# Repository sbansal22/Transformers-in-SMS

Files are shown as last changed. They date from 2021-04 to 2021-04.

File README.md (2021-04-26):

# Transformers-in-SMS
Transformers in SMS (CC1310-01) Olin 2020-2021 Co-Curricular

#### Schematic
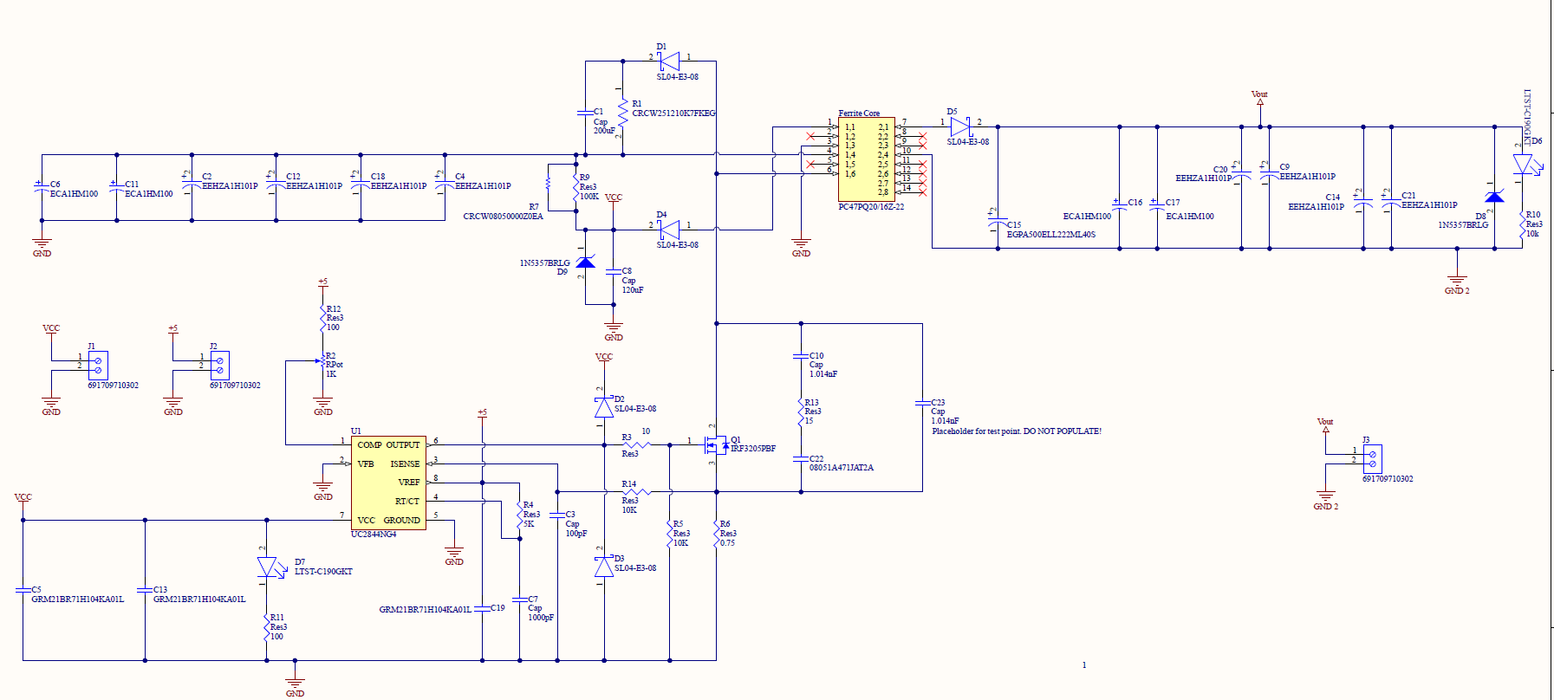
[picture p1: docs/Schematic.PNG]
Schematic


#### Routing
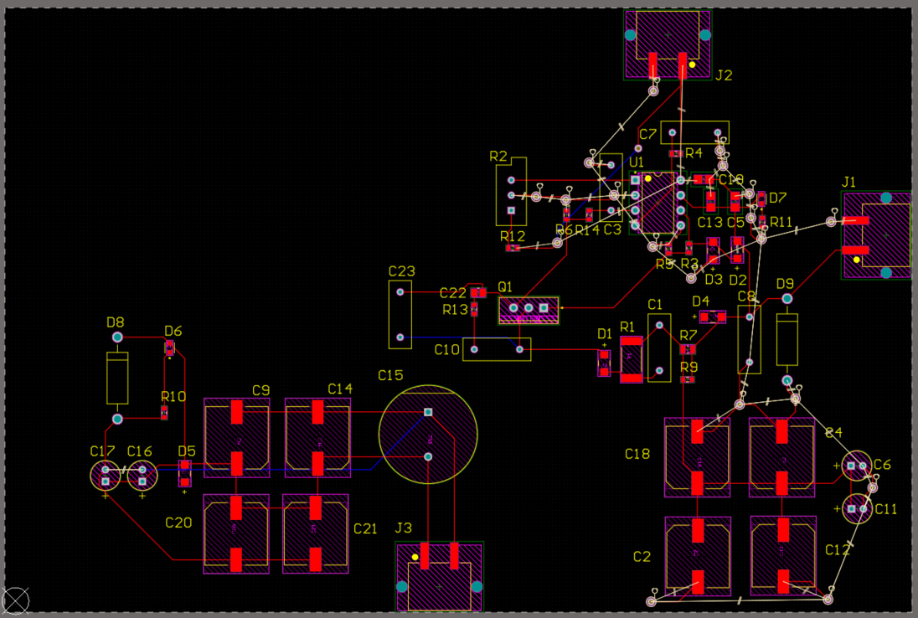
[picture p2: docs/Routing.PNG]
Routing


#### Layout
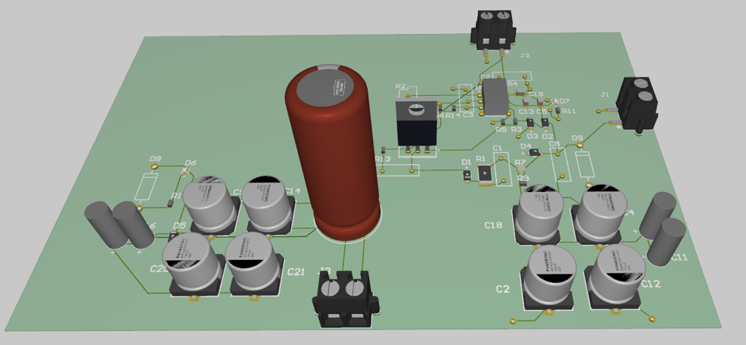
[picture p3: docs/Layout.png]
Layout


## Ordering PCBs From JLCPCB

For ordering the boards, go to JLCPCB.com (https://jlcpcb.com/RAT), and click on "Quote Now" button.

jlcpcb quote

JLCPCB (ShenzhenJLC Electronics Co., Ltd.), is the largest PCB prototype enterprise in China, and a high-tech manufacturer specializing in quick PCB prototype and small-batch PCB production. You can order a minimum of 5 PCBs for just $2.

First: Upload the gerber files for the board by clicking the "Add gerber file" button. You’ll notice a message at the bottom if the file is successfully uploaded.

jlcpbc gerber

A correctly uploaded gerber folder renders the board as follows:

jlcpcb render

Second: In order to get the board assembled (optional, based on the project requirements), select the "SMT Assembly option. It is important to select the side of the PCB that needs to be assembled, as well as the quantity for SMT. Press the "Confirm" button, then press the "Next" button.

jlcpcb smt

Third: upload the BOM (Bill of Material) and CPL (Component Placement List) files and click the "Next" button. It is necessary to make sure that each of these files follow the jlcpcb specified BOM and CPL formats, respectively:

- [Sample BOM](https://jlcpcb.com//video/JLCSMT_Sample_BOM1.xlsx?_ga=2.42560357.1905056644.1612161700-100444678.1610257845)
- [Sample CPL](https://jlcpcb.com//video/JLCSMT_Sample_CPL1.xlsx?_ga=2.42560357.1905056644.1612161700-100444678.1610257845)
- [SMT FAQ's](https://support.jlcpcb.com/category/78-smt-assembly?_ga=2.42560357.1905056644.1612161700-100444678.1610257845)

Note: If there is an issue with the BOM/CPL formatting, the the page will keep erroring out until it is resolved.

jlcpcb bom

Fourth: The parts are automatically detected through the uploaded BOM. They are also matched against jlcpcb's in-stock parts. It is important to go through each row and confirm if the auto-detected parts are the desired parts. Some parts will remain undetected if they cannot be assembled through SMT and require manual assembly post-deilvery.

jlcpcb parts

Fifth: The website renders an assembled board using the CPL file. This feature can be used to review the placement of the components (including orientation). Once carefull reviewed, the next step is to download a list of parts remaining to be assembled towards the bottom of this page view. It is important to place an order for the remaining components to be manually assembled upon delivery.

jlcpcb review

Sixth: Click on the “Save to Cart” button. Then, click on the "Secure Checkout" button.

jlcpcb checkout

Last: Add the payment details and choose the suitable delivery method (this includes FedEx, DHL, and standard mail options). Then, place the order.

Optional: To review the production status of the board, click on the "Order History" button under username. Then, click on In Production > view progress to obtain timestamps for each of the production steps in real time.

jlcpcb production

jlcpcb production progress

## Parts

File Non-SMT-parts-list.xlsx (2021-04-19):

Designator | Comment | Footprint | Quantity
D2,D3,D5,D6,D7 | SS2FL4-M3/H | SODFL3718X108N | 5
R10 | CRCW251210K7FKEG | CRCW251210K7FKEG | 1
C8,C9,C10,C11,C20,C21,C22,C23 | EEHZA1H101P | CAPAE1030X1050N | 8
C1,C2,C3 | GRM21BR71H104KA01L | 0805_C | 3
U2 | PC47PQ20_16Z-22 | CPVPQ20161S14PZ | 0
J4 | CONN_01X02_MALE | PINHEADER_1X02_P2.54MM_VERTICAL | 0
Q1 | IRF3205 | TO-220-3_VERTICAL | 0
C6,C7,C18,C19 | ECA1HM100 | CAPPRD200W50D500H1100B | 0
C13 | 120UF | CAPPRD500W60D1000H1800 | 0
U1 | UC2844NG4 | DIP794W45P254L959H508Q8 | 0
D4,D8 | 1N5357BRLG | DIOAD1720W120L750D440P | 0
DESIGNATOR | COMMENT | FOOTPRINT | 0
J1,J2,J3 | SCREW_TERMINAL_01X02 | TERMINALBLOCK_PHOENIX_MKDS-1,5-2_1X02_P5.00MM_HORIZONTAL | 0
VR1 | 3362P-1-102LF | TRIM_3362P-1-102LF | 0

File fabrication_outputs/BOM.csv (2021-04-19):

Comment | Designator | Footprint | LCSC Part # | LCSC Part Type
PC47PQ20_16Z-22 | U2 | CPVPQ20161S14PZ
GRM21BR71H104KA01L | C1,C2,C3 | 0805_C
1000pF | C4 | 0805_C
100pF | C5 | 0805_C
EEHZA1H101P | C8,C9,C10,C11,C20,C21,C22,C23 | CAPAE1030X1050N
1.014nF | C14 | 0805_C
08051A471JAT2A | C15 | 0805_C
EGPA500ELL222ML40S | C17 | C_Elec_10x10.2
Screw_Terminal_01x02 | J1,J2,J3 | TerminalBlock_Phoenix_MKDS-1,5-2_1x02_P5.00mm_Horizontal
IRF3205 | Q1 | TO-220-3_Vertical
100 | R1 | R_0805_OEM
R_100 | R2 | R_0805_OEM
R_4.7K | R3 | R_0805_OEM
10 | R4 | R_0805_OEM
10K | R5,R6 | R_0805_OEM
0.05 | R7 | R_0805_OEM
CRCW08050000Z0EA | R8 | CRCW08050000Z0EA
R_100K | R9 | R_0805_OEM
CRCW251210K7FKEG | R10 | CRCW251210K7FKEG
15 | R11 | R_0805_OEM
R_10K | R12 | R_0805_OEM
UC2844NG4 | U1 | DIP794W45P254L959H508Q8
ECA1HM100 | C6,C7,C18,C19 | CAPPRD200W50D500H1100B
LTST-C190GKT | D1,D9 | LEDM1608X80
SS2FL4-M3/H | D2,D3,D5,D6,D7 | SODFL3718X108N
1N5357BRLG | D4,D8 | DIOAD1720W120L750D440P
3362P-1-102LF | VR1 | TRIM_3362P-1-102LF
Conn_01x02_Male | J4 | PinHeader_1x02_P2.54mm_Vertical
120uF | C13 | CAPPRD500W60D1000H1800
200uF | C12 | CAPAE1350X1400N

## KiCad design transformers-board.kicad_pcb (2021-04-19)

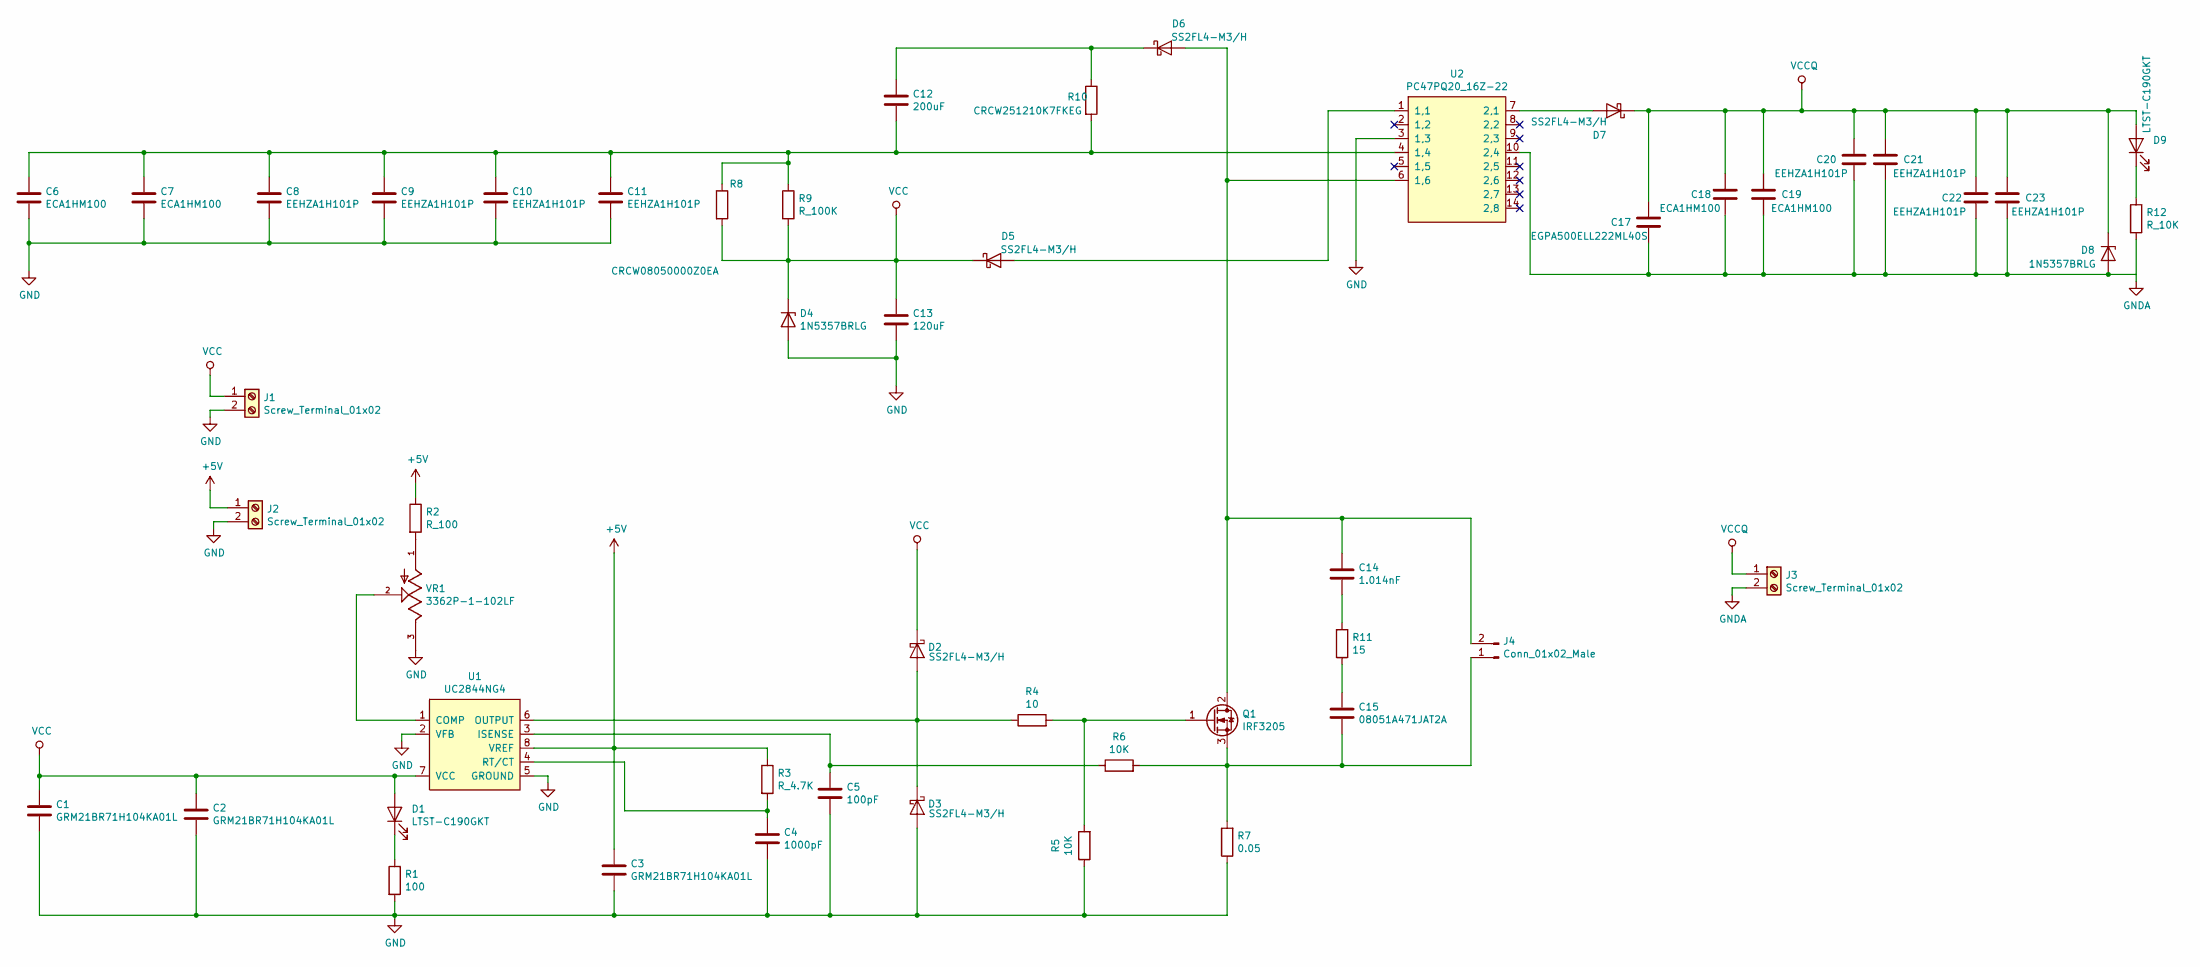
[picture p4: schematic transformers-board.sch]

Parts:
C1, C2, C3: GRM21BR71H104KA01L; C_0805_2012Metric
C4: 1000pF; C_0805_2012Metric
C5: 100pF; C_0805_2012Metric
C6, C7, C18, C19: ECA1HM100; CAPPRD200W50D500H1100B
C8, C9, C10, C11, C20, C21, C22, C23: EEHZA1H101P; CAPAE1030X1050N
C12: 200uF; CAPAE1350X1400N
C13: 120uF; CAPPRD500W60D1000H1800
C14: 1.014nF; C_0805_2012Metric
C15: 08051A471JAT2A; C_0805_2012Metric
C17: EGPA500ELL222ML40S; C_Elec_10x10.2
D1, D9: LTST-C190GKT; LEDM1608X80
D2, D3, D5, D6, D7: SS2FL4-M3/H; SODFL3718X108N
D4, D8: 1N5357BRLG; DIOAD1720W120L750D440P
J1, J2, J3: Screw_Terminal_01x02; TerminalBlock_Phoenix_MKDS-1,5-2_1x02_P5.00mm_Horizontal
J4: Conn_01x02_Male; PinHeader_1x02_P2.54mm_Vertical
Q1: IRF3205; TO-220-3_Vertical
R1: 100; R_0805_OEM; MPN RNCP0805FTD100RCT-ND
R2: R_100; R_0805_OEM; MPN RNCP0805FTD100RCT-ND
R3: R_4.7K; R_0805_OEM; MPN 311-4.7KARCT-ND
R4: 10; R_0805_OEM; MPN RNCP0805FTD100RCT-ND
R5, R6: 10K; R_0805_OEM; MPN RNCP0805FTD100RCT-ND
R7: 0.05; R_0805_OEM; MPN RNCP0805FTD100RCT-ND
R8: CRCW08050000Z0EA
R9: R_100K; R_0805_OEM; MPN P100KCCT-ND
R10: CRCW251210K7FKEG
R11: 15; R_0805_OEM; MPN RNCP0805FTD100RCT-ND
R12: R_10K; R_0805_OEM; MPN CRS0805-FX-1002ELFCT-ND
U1: UC2844NG4; DIP794W45P254L959H508Q8
U2: PC47PQ20_16Z-22; CPVPQ20161S14PZ
VR1: 3362P-1-102LF; TRIM_3362P-1-102LF; PARTREV 08/26/10

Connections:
+5V: C3.1, J2.1, R2.1, R3.1, U1.8 (VREF)
GND: C1.2, C2.2, C3.2, C4.2, C5.2, C6.2, C7.2, C8.2, C9.2, C10.2, C11.2, C13.2, D3.2 (A), D4.2 (A), J1.2, J2.2, R1.2, R5.1, R7.1, U1.2 (VFB), U1.5 (GROUND), U2.3 (1,3), VR1.3
GNDA: C17.2, C18.2, C19.2, C20.2, C21.2, C22.2, C23.2, D8.2 (A), J3.2, R12.2, U2.10 (2,4)
unnamed: C4.1, R3.2, U1.4 (RT/CT)
unnamed: C5.1, R6.1, U1.3 (ISENSE)
unnamed: C6.1, C7.1, C8.1, C9.1, C10.1, C11.1, C12.2, R8.1, R9.1, R10.2, U2.4 (1,4)
unnamed: C12.1, D6.1 (K), R10.1
unnamed: C14.1, D6.2 (A), J4.2, Q1.2 (D), U2.6 (1,6)
unnamed: C14.2, R11.2
unnamed: C15.1, R11.1
unnamed: C15.2, J4.1, Q1.3 (S), R6.2, R7.2
unnamed: D1.1 (K), R1.1
unnamed: D2.2 (A), D3.1 (K), R4.1, U1.6 (OUTPUT)
unnamed: D5.2 (A), U2.1 (1,1)
unnamed: D7.2 (A), U2.7 (2,1)
unnamed: D9.1 (K), R12.1
unnamed: Q1.1 (G), R4.2, R5.2
unnamed: R2.2, VR1.1
unnamed: U1.1 (COMP), VR1.2
VCC: C1.1, C2.1, C13.1, D1.2 (A), D2.1 (K), D4.1 (K), D5.1 (K), J1.1, R8.2, R9.2, U1.7 (VCC)
VCCQ: C17.1, C18.1, C19.1, C20.1, C21.1, C22.1, C23.1, D7.1 (K), D8.1 (K), D9.2 (A), J3.1

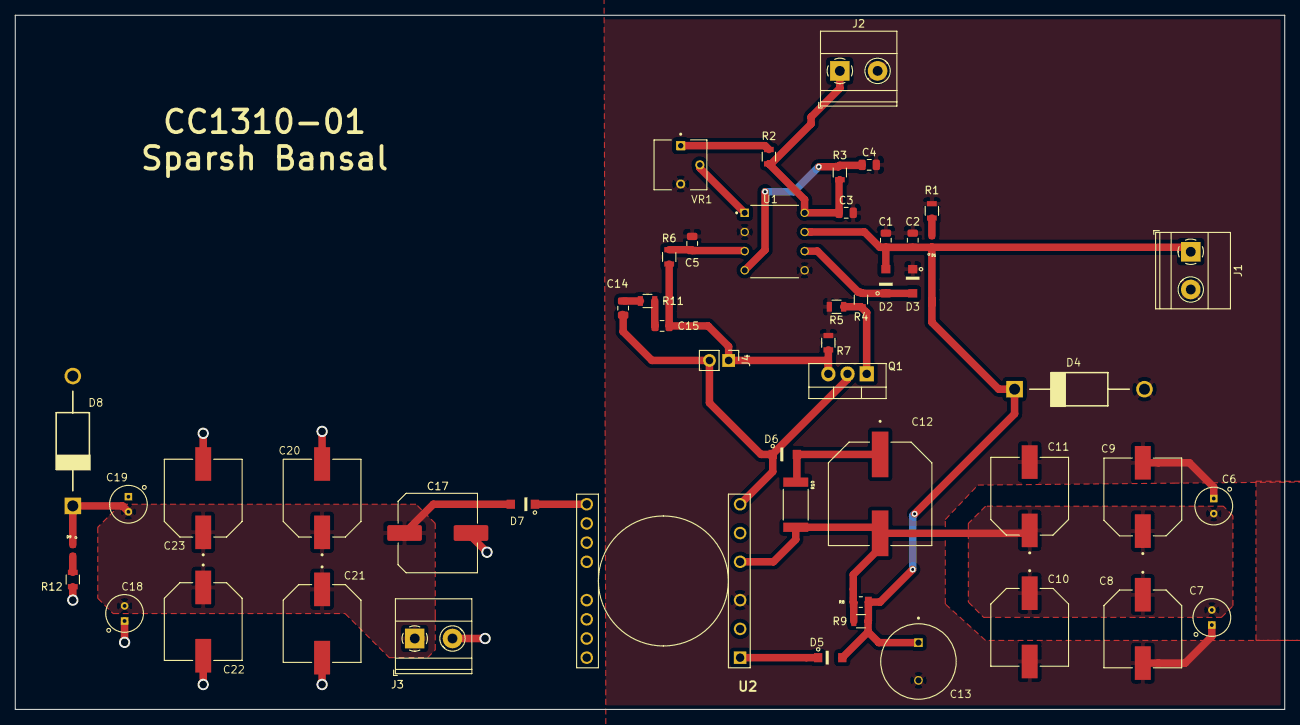
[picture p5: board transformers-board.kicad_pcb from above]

Board: 2 copper layers, 168.1 x 91.9 mm, 51 parts (0 on the bottom side), 21 nets.

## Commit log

2021-04-03 Add initial KiCAD board files
    [transformers-board.kicad_pcb, transformers-board.sch]
2021-04-04 Add layout updates
    [transformers-board.kicad_pcb, transformers-board.sch]
2021-04-09 Make changes for Beat's comments
    [transformers-board.kicad_pcb, transformers-board.sch]
2021-04-19 Add fabrication outputs
    [Non-SMT-parts-list.xlsx, transformers-board.kicad_pcb, transformers-board.sch]
2021-04-19 Add gerbers
    [transformers-board-B_Cu.gbr, transformers-board-B_Mask.gbr, transformers-board-B_Paste.gbr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]
2021-04-19 Add fabrication outputs (for real this time)
    [BOM.csv, kicadbom.csv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]
